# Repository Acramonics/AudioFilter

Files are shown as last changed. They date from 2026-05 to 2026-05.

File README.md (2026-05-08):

Audio Multi Filter
==================

Drawings and PCB (c) 2026 Andrew Martin, acramonics
---------------------------------------------------

This is an implementation of Jake Rothman's **Audio Multi Filter**
described in *Practical Electronics*, May 2026.

This circuit provides High-Pass, Low-Pass, Band-Pass, Notch and
All-Pass filters on a single circuit by combining combinations of
High-Pass and Low-Pass outputs.

In addition to the hardware on the board, my design requires:

- a 3P6T rotary switch,
- a DPDT (or DPST) toggle switch,
- a 10K anti-log pot,
- a dual 100K anti-log pot.

Power Supply
------------

The design includes power smoothing, but will need a dual rail power
supply providing somewhere between +/-12V and +/-18V.

Hardware
--------

### 3P6T rotary switch

The classical wafer switches are *extremely* expensive from UK
suppliers, typically #30.00 upwards per wafer! However, I have found
them at a very reasonable price (~#4.00) from AliExpress.

You could also use a 3P5T switch and replace the 1st straight through
position ('Thru') with another toggle switch.

For a stereo version, either build two boards, or if you want the same
output on both channels, you could use a 6P6T switch (if you can find
one), or a 6P5T switch (which I have seen on AliExpress at ~#5.00) and
a toggle switch to replace the Thru position.

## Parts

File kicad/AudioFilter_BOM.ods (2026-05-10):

Reference | Qty | Value | Footprint
C1 | 1 | 1uF 16V Audio | Capacitor_THT:CP_Radial_D5.0mm_P2.00mm
C2 | 1 | 220uF 16V Audio | Capacitor_THT:CP_Radial_D6.3mm_P2.50mm
C3,C6 | 2 | 100uF 16V Audio | Capacitor_THT:CP_Radial_D6.3mm_P2.50mm
C4,C7 | 2 | 100nF PP | Capacitor_THT:C_Rect_L7.0mm_W3.5mm_P5.00mm
C18,C19,C20 | 3 | 100nF PE | Capacitor_THT:C_Rect_L7.0mm_W3.5mm_P5.00mm
C5,C8 | 2 | 6.8nF PP | Capacitor_THT:C_Rect_L7.0mm_W3.5mm_P5.00mm
C9,C10,C14 | 5 | 10uF 10V | Capacitor_THT:CP_Radial_D5.0mm_P2.00mm
C16,C17 | 5 | 10uF 25V | Capacitor_THT:CP_Radial_D5.0mm_P2.00mm
C11,C12,C13 | 3 | 47pF Ceramic | Capacitor_THT:C_Disc_D5.0mm_W2.5mm_P5.00mm
C15 | 1 | 470nF PP | Capacitor_THT:C_Rect_L7.0mm_W3.5mm_P5.00mm
J1,J2,J3,J5,J10 | 5 | Conn_01x02_Pin | Connector_Molex:Molex_KK-254_AE-6410-02A_1x02_P2.54mm_Vertical
J4,J7,J8 | 3 | Conn_01x04_Pin | Connector_Molex:Molex_KK-254_AE-6410-04A_1x04_P2.54mm_Vertical
J6 | 1 | Conn_01x03_Pin | Connector_Molex:Molex_KK-254_AE-6410-03A_1x03_P2.54mm_Vertical
J9 | 1 | Conn_01x07_Pin | Connector_Molex:Molex_KK-254_AE-6410-07A_1x07_P2.54mm_Vertical
R1,R2,R18,R19,R21 | 5 | 22K | Resistor_THT:R_Axial_DIN0207_L6.3mm_D2.5mm_P10.16mm_Horizontal
R3 | 1 | 4K7 | Resistor_THT:R_Axial_DIN0207_L6.3mm_D2.5mm_P10.16mm_Horizontal
R4,R7 | 2 | 620R | Resistor_THT:R_Axial_DIN0207_L6.3mm_D2.5mm_P10.16mm_Horizontal
R5,R8 | 2 | 330K | Resistor_THT:R_Axial_DIN0207_L6.3mm_D2.5mm_P10.16mm_Horizontal
R6,R9,R20,R22 | 4 | 470R | Resistor_THT:R_Axial_DIN0207_L6.3mm_D2.5mm_P10.16mm_Horizontal
R10,R11,R12,R17 | 4 | 100R | Resistor_THT:R_Axial_DIN0207_L6.3mm_D2.5mm_P10.16mm_Horizontal
R13,R14,R15 | 3 | 10K | Resistor_THT:R_Axial_DIN0207_L6.3mm_D2.5mm_P10.16mm_Horizontal
R16 | 1 | 12K | Resistor_THT:R_Axial_DIN0207_L6.3mm_D2.5mm_P10.16mm_Horizontal
RV1 | 1 | C10K
RV2 | 1 | C100K_Dual
RV3 | 1 | 1K | Potentiometer_THT:Potentiometer_Vishay_T73YP_Vertical
SW1 | 1 | SW_DPDT_x2
SW2 | 1 | SW_Rotary_1x6_MP
U1,U2 | 2 | NE5532
U3 | 1 | NE5534

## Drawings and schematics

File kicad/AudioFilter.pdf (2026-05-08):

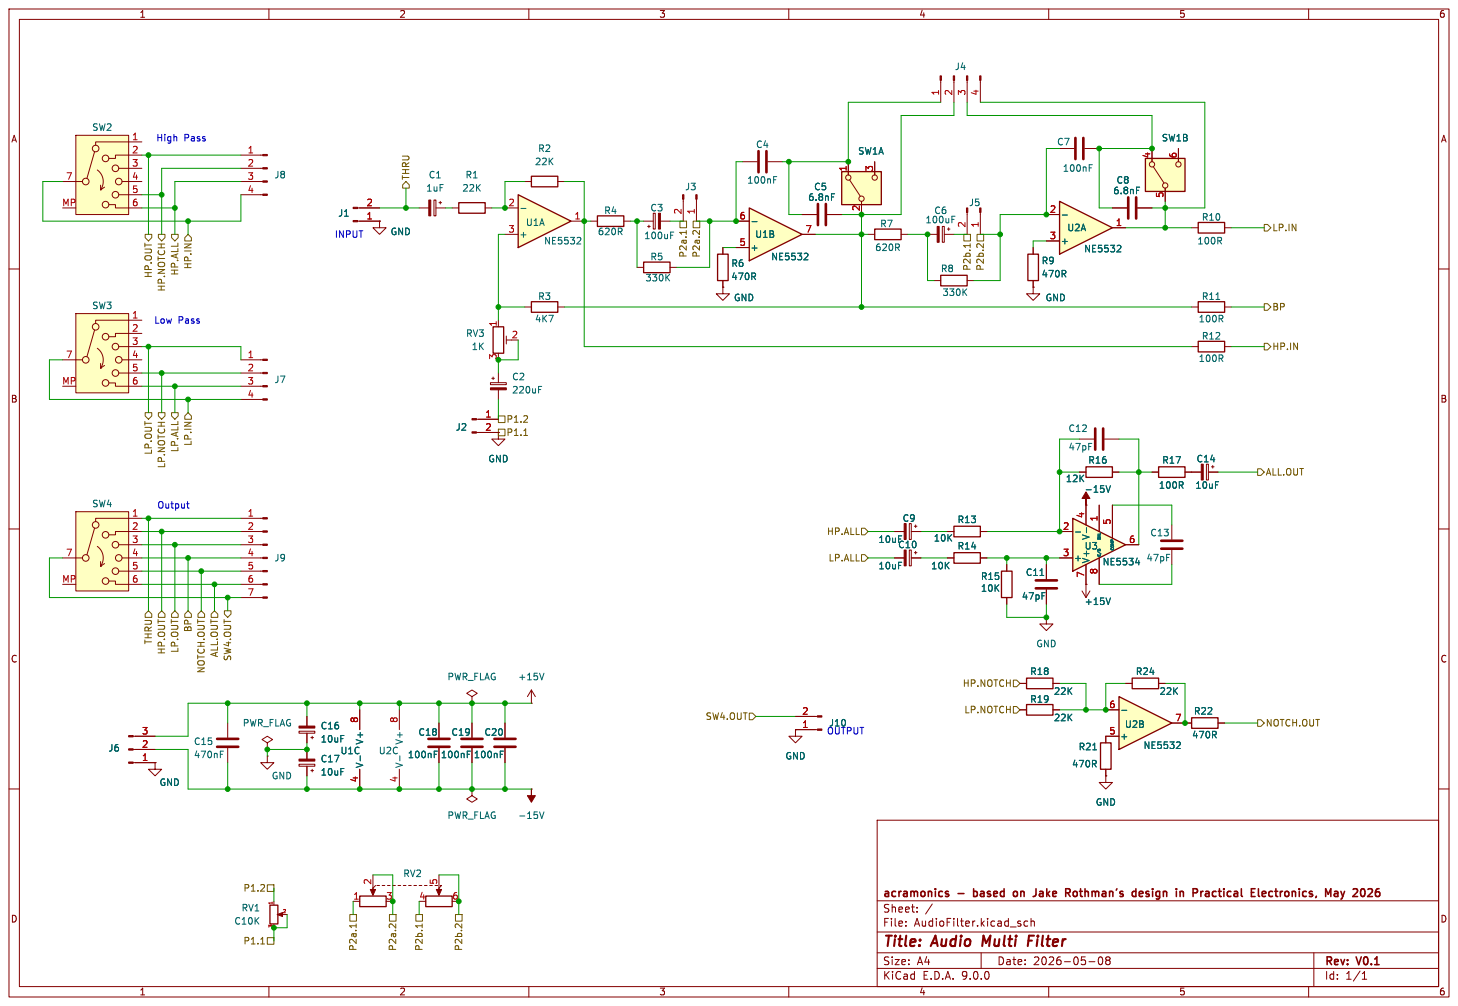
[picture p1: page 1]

NOTCH.OUT P1.1 P1.2 HP.NOTCH

ALL.OUT P2b.1 HP.ALL P2a.2

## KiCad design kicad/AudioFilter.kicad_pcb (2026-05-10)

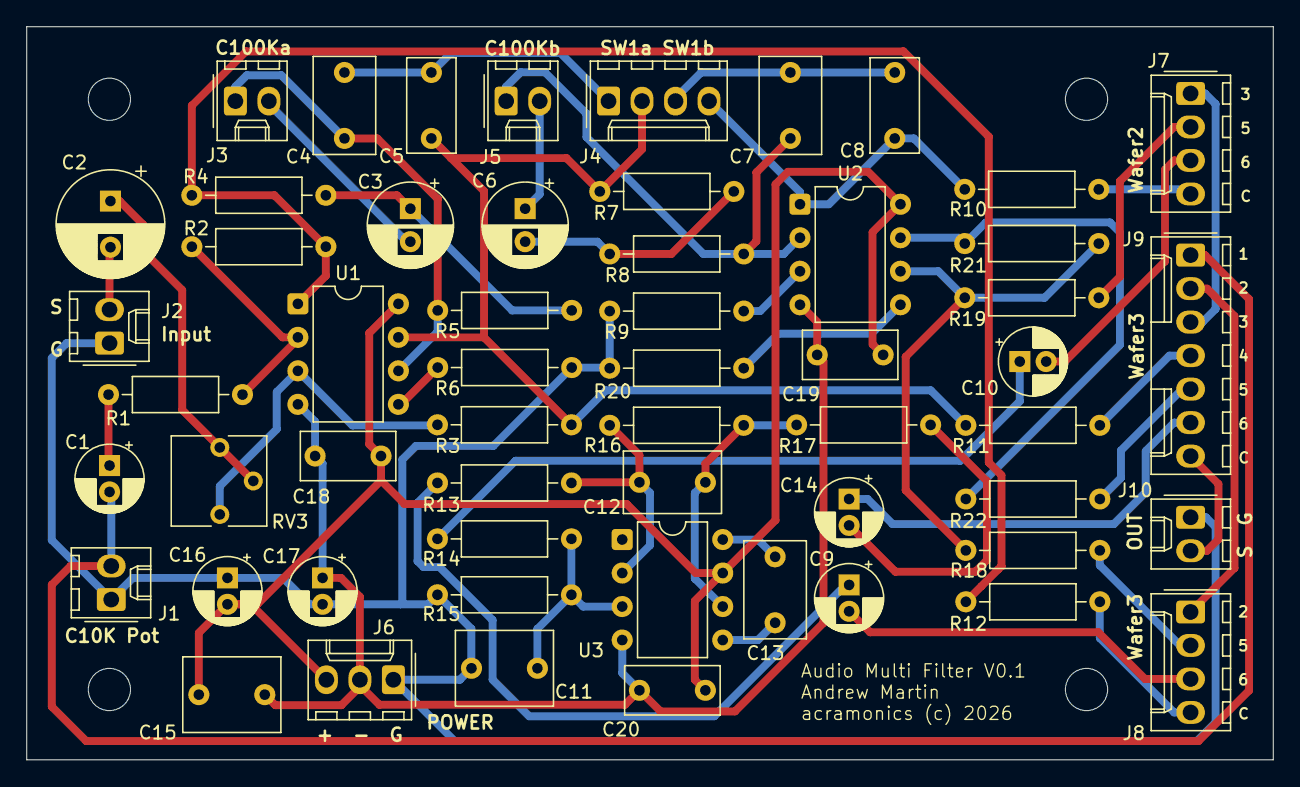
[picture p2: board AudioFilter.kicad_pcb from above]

Board: 2 copper layers, 94.5 x 55.6 mm, 56 parts (0 on the bottom side), 45 nets.

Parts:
C1: 1uF 16V A; CP_Radial_D5.0mm_P2.00mm
C2: 220uF 25V A; CP_Radial_D8.0mm_P3.50mm
C3, C6: 100uF 25V A; CP_Radial_D6.3mm_P2.50mm
C4, C7: 100nF PP; C_Rect_L7.2mm_W4.5mm_P5.00mm_FKS2_FKP2_MKS2_MKP2
C5, C8: 6.8nF PP; C_Rect_L7.0mm_W3.5mm_P5.00mm
C9, C10: 10uF 16V; CP_Radial_D5.0mm_P2.00mm
C11: 47pF PP; C_Rect_L7.2mm_W5.5mm_P5.00mm_FKS2_FKP2_MKS2_MKP2
C12, C13: 47pF PP; C_Rect_L7.2mm_W4.5mm_P5.00mm_FKS2_FKP2_MKS2_MKP2
C14: 10uF; CP_Radial_D5.0mm_P2.00mm
C15: 470nF; C_Rect_L7.2mm_W5.5mm_P5.00mm_FKS2_FKP2_MKS2_MKP2
C16, C17: 10uF 25V; CP_Radial_D5.0mm_P2.00mm
C18, C19, C20: 100nF; C_Rect_L7.0mm_W3.5mm_P5.00mm
J1, J2, J3, J5, J10: Conn_01x02_Pin; Molex_KK-254_AE-6410-02A_1x02_P2.54mm_Vertical
J4, J7, J8: Conn_01x04_Pin; Molex_KK-254_AE-6410-04A_1x04_P2.54mm_Vertical
J6: Conn_01x03_Pin; Molex_KK-254_AE-6410-03A_1x03_P2.54mm_Vertical
J9: Conn_01x07_Pin; Molex_KK-254_AE-6410-07A_1x07_P2.54mm_Vertical
R1, R2, R18, R19, R21: 22K; R_Axial_DIN0207_L6.3mm_D2.5mm_P10.16mm_Horizontal
R3: 4K7; R_Axial_DIN0207_L6.3mm_D2.5mm_P10.16mm_Horizontal
R4, R7: 620R; R_Axial_DIN0207_L6.3mm_D2.5mm_P10.16mm_Horizontal
R5, R8: 330K; R_Axial_DIN0207_L6.3mm_D2.5mm_P10.16mm_Horizontal
R6, R9, R20, R22: 470R; R_Axial_DIN0207_L6.3mm_D2.5mm_P10.16mm_Horizontal
R10, R11, R12, R17: 100R; R_Axial_DIN0207_L6.3mm_D2.5mm_P10.16mm_Horizontal
R13, R14, R15: 10K; R_Axial_DIN0207_L6.3mm_D2.5mm_P10.16mm_Horizontal
R16: 12K; R_Axial_DIN0207_L6.3mm_D2.5mm_P10.16mm_Horizontal
RV3: 1K; Potentiometer_Vishay_T73YP_Vertical
U1, U2: NE5532; DIP-8_W7.62mm
U3: NE5534; DIP-8_W7.62mm

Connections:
+15V: C15.2, C16.2, C18.2, C19.2, C20.2, J6.3, U1.8 (V+), U2.8 (V+), U3.7 (V+)
-15V: C15.1, C17.1, C18.1, C19.1, C20.1, J6.2, U1.4 (V-), U2.4 (V-), U3.4 (V-)
/ALL.OUT: C14.1, J9.6
/BP: J9.4, R11.1
/HP.ALL: C9.2, J8.3
/HP.IN: J8.4, R12.1
/HP.NOTCH: J8.2, R18.2
/HP.OUT: J8.1, J9.2
/LP.ALL: C10.2, J7.3
/LP.IN: J7.4, R10.1
/LP.NOTCH: J7.2, R19.2
/LP.OUT: J7.1, J9.3
/NOTCH.OUT: J9.5, R22.1
/P1.2: C2.2, J2.2
/P2a.1: C3.2, J3.2
/P2a.2: C4.1, J3.1, R5.2, U1.6 (-)
/P2b.1: C6.1, J5.2
/P2b.2: C7.1, J5.1, R8.2, U2.2 (-)
/SW4.OUT: J9.7, J10.2
/THRU: C1.2, J1.2, J9.1
GND: C11.1, C16.1, C17.2, J1.1, J2.1, J6.1, J10.1, R6.1, R9.1, R15.2, R20.2
unnamed: C1.1, R1.1
unnamed: C2.1, RV3.2, RV3.3
unnamed: C3.1, R4.2, R5.1
unnamed: C6.2, R7.2, R8.1
unnamed: C9.1, R13.2
unnamed: C10.1, R14.2
unnamed: C12.2, R16.2, R17.2, U3.6
unnamed: C14.2, R17.1
unnamed: C4.2, C5.1, J4.1
unnamed: C5.2, J4.2, R3.2, R7.1, R11.2, U1.7
unnamed: C7.2, C8.1, J4.3
unnamed: C8.2, J4.4, R10.2, U2.1
unnamed: R2.2, R4.1, R12.2, U1.1
unnamed: R21.1, R22.2, U2.7
unnamed: R3.1, RV3.1, U1.3 (+)
unnamed: R1.2, R2.1, U1.2 (-)
unnamed: R6.2, U1.5 (+)
unnamed: R9.2, U2.3 (+)
unnamed: R20.1, U2.5 (+)
unnamed: R18.1, R19.1, R21.2, U2.6 (-)
unnamed: C11.2, R14.1, R15.1, U3.3 (+)
unnamed: C12.1, R13.1, R16.1, U3.2 (-)
unnamed: C13.2, U3.5 (COMP)
unnamed: C13.1, U3.8 (C/B)

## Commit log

2026-05-08 Visual layout tweaks
    [AudioFilter.kicad_pcb, AudioFilter.kicad_sch]
2026-05-08 Some tidying up
    [AudioFilter.kicad_pcb, AudioFilter.kicad_sch, AudioFilter_BOM.ods]
2026-05-10 Component size adjustments
    [AudioFilter.kicad_pcb, AudioFilter.kicad_sch, AudioFilter_BOM.ods]

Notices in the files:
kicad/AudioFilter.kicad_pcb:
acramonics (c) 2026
